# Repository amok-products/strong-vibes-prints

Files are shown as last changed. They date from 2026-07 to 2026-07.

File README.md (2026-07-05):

# Strong Vibes Prints

Parametric [build123d](https://build123d.readthedocs.io/) (Python CAD) parts for
mounting a massager, all sharing one mating interface: **Strong Vibes Connect**.
A keyed rhombus/diamond boss (MALE) plugs into a matching diamond socket (FEMALE)
and is clamped by a single 1/4"-20 camera/tripod screw. The interface is defined
exactly once in the `strongvibes` package (`DIA_A`, `DIA_B`, `BAND_DEPTH`) and
every part imports it, so the connection can never drift — any boss plugs into any
socket, forever.

Part of the [**Strong Vibes**](https://github.com/amok-products/strong-vibes)
open builder program by [Europe Magic Wand®](https://europemagicwand.com/strong-vibes-builder).

> **Interactive 3D:** spin every part in your browser at
> **[amok-products.github.io/strong-vibes-prints](https://amok-products.github.io/strong-vibes-prints/)**.

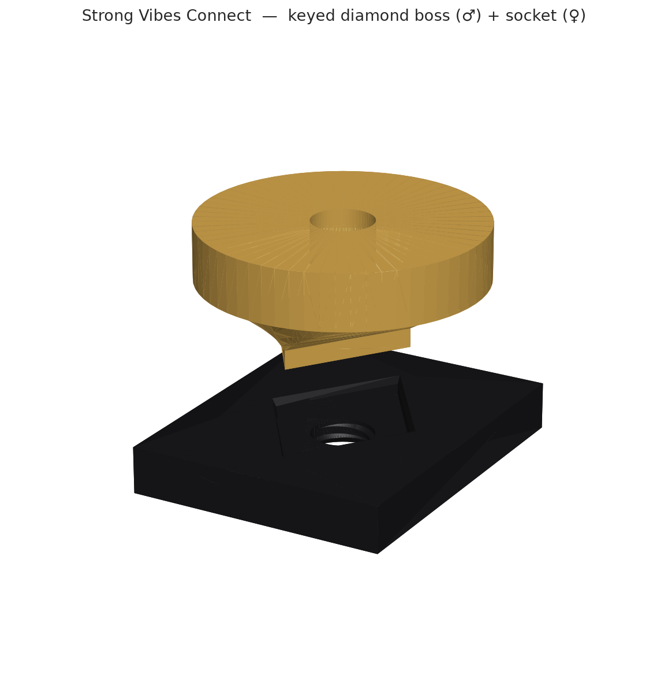
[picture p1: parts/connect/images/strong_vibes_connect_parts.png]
Strong Vibes Connect


---

## Parts

| Part | Role | Description | Folder |
|---|---|---|---|
| **Holder** | MALE | Snap-fit device holder with a Strong Vibes Connect diamond boss. | [`parts/holder/`](parts/holder/) |
| **Connect** | both | Bench-test set: `strong_vibes_socket_180` + `strong_vibes_socket_30` + a male test boss — print these to validate the interface. | [`parts/connect/`](parts/connect/) |

Everything mates through **Strong Vibes Connect**, so these parts interoperate
with any other part built to the standard.

---

## Print a part

These parts are **parametric source** — you build exactly the fit you want.
Blessed ready-to-print exports land in `parts/<part>/release/` as they're cut; if
a `release/` folder is empty, build from source (below) to generate the files.

1. **Preview first.** Spin any part in the
   [interactive 3D viewer](https://amok-products.github.io/strong-vibes-prints/).
2. **Get an export.** Grab a `.stl` (drop straight into a slicer) or `.step`
   (solid model to re-orient/tweak) from `parts/<part>/release/`, or build one
   (see [Build from source](#build-from-source) and [`EXPORTING.md`](EXPORTING.md)).
3. **Slice it** in **Bambu Studio** or **PrusaSlicer**.
4. **Material** — the holder is for **Europe Magic Wand®** models, tested in Bambu
   Lab **TPU for AMS (68D)** or **PLA Tough**; ordinary PLA will crack. For a perfect
   holder fit, add a **4 cm strip of Bambu Lab non-slip tape** to the lower back.
   Sockets print fine in PLA Tough.
5. **Orientation:** print the holder boss horizontal / device axis vertical, as
   exported.

The joint is assembled with one **1/4"-20 × 9–10 mm** camera/tripod screw (Bambu
Lab). With `FEMALE_THREAD` on, the socket is tapped so the screw stays captive.

---

## The Strong Vibes Connect interface

A keyed **diamond (rhombus) boss** seats flat into a matching **diamond socket**
and is clamped by a **1/4"-20 screw** down the joint axis. The diamond is keyed
(long axis ≠ short axis), so the boss seats in a single orientation (mod 180°).

The standard is the constant cross-section of the diamond, defined once in
`strongvibes/`:

- `DIA_A = 11.322 mm` — long half-diagonal
- `DIA_B = 7.759 mm` — short half-diagonal
- `BAND_DEPTH = 2.0 mm` — the constant-section band the socket grips
- **1/4"-20** thread spec — `THREAD_MAJOR = 6.35`, `THREAD_PITCH = 1.27`

Two socket variants exist:

- **`strong_vibes_socket_180`** — keyed single-orientation pocket (the default).
  One diamond, one way in.
- **`strong_vibes_socket_30`** — a star pocket (the diamond unioned every 30°)
  that accepts the boss every 30° for **stepwise rotational mounting**.

Every part imports these from the `strongvibes` package, so the connection is
inherited, never re-derived. Change the standard in one place and every part
follows. The interface is published as the
[**Strong Vibes Connect** standard](https://github.com/amok-products/strong-vibes/blob/main/connect/strong-vibes-connect.md)
in the umbrella repo.

---

## Build from source

The parts are real Python — open one, change a parameter, and watch the 3D model
update live.

1. **Python + dependencies.** Install **Python 3.13** (the project pins
   `>=3.13,<3.14`), then:

   ```bash
   python3.13 -m venv .venv
   source .venv/bin/activate            # Windows: .venv\Scripts\activate
   pip install -r requirements.txt
   pip install -e .                     # wires up the shared `strongvibes` package
   ```

2. **OCP CAD Viewer.** Install the **OCP CAD Viewer** VS Code extension. It pairs
   with the `ocp_vscode` package (already in `requirements.txt`) and shows the
   live 3D preview on **port 3939**. Viewer settings (autostart, port, dark
   theme, axes, grid) are committed in [`.vscode/settings.json`](.vscode/settings.json).

3. **Run & export.** Open a part's `.py`, Run it, and the live 3D preview updates
   in the OCP CAD Viewer. A plain run previews only; prefix `SV_EXPORT=1` to also
   write `.step`, `.stl`, and `.3mf` to the gitignored **`build/`** working dir
   (via `strongvibes.build_path()`). Slice the result in Bambu Studio /
   PrusaSlicer. See [`EXPORTING.md`](EXPORTING.md) for the full preview/export
   workflow and how release files are blessed.

   ```bash
   python parts/holder/strong_vibes_holder.py               # preview only
   SV_EXPORT=1 python parts/holder/strong_vibes_holder.py   # also write build/
   ```

   > **3MF note:** for threaded parts the `.3mf` write is best-effort —
   > `lib3mf`'s strict manifold check can reject the helical thread mesh even
   > when the solid is valid. Use the **`.stl`** or **`.step`** (slicers re-mesh
   > fine).

### Modify with an AI assistant

The parts are parametric, so natural-language edits work well. A realistic prompt:

> *"In `parts/holder/strong_vibes_holder.py`, make the boss buttress taller for
> strength — set `boss_aspect` to 1.4 — without changing the Strong Vibes Connect
> mating diamond. Then rebuild and confirm it's valid."*

`boss_aspect` (default `1.5`) stretches only the structural flare **behind** the
diamond band; the mating diamond stays the standard `DIA_A` / `DIA_B`, so the
connection never changes.

> **Locked:** the mating diamond (`DIA_A`, `DIA_B`, `BAND_DEPTH`) is the shared
> standard and must **not** change in a single part — that would break
> compatibility with every other part. Changing it is a repo-wide interface event
> (see [`AGENTS.md`](AGENTS.md)).

---

## Repo layout

```
strongvibes/             shared library = the Strong Vibes Connect standard (install: pip install -e .)
parts/holder/            strong_vibes_holder.py — snap-fit device holder, MALE diamond boss
parts/connect/           connect_test.py — bench-test set: strong_vibes_socket_180 + strong_vibes_socket_30 + strong_vibes_boss
  parts/<part>/images/   committed renders
  parts/<part>/release/  committed STL/STEP users download (no build needed)
docs/                    interactive 3D landing page (GitHub Pages) + the .glb models it loads
build/                   gitignored working dir — exports land here while iterating
AGENTS.md                versioning + commit conventions for parts
```

---

## Licensing

- The parametric build123d **source and the models it generates** are licensed
  **[CC-BY-4.0](LICENSE)** — free to use, adapt, and print, including
  commercially, with attribution.
- Third-party dependencies keep their own licenses — see [`ATTRIBUTION.md`](ATTRIBUTION.md).
- The **names** ("Strong Vibes", "Europe Magic Wand®") are governed by
  [`TRADEMARK.md`](TRADEMARK.md).

See [`DISCLAIMER.md`](DISCLAIMER.md) before building or using anything. Versioning
and commit conventions live in [`AGENTS.md`](AGENTS.md).

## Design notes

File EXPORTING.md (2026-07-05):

# Exporting parts

Every part is a parametric build123d script. There are exactly **two ways to run
one**, selected by the `SV_EXPORT` environment variable — no file editing:

| Workflow | Command | What it does |
|---|---|---|
| **Preview** (default) | `python parts/<part>/<file>.py` | Builds the solid, prints validity + interface dims, shows it live in the OCP CAD Viewer. **Writes no files.** |
| **Export** | `SV_EXPORT=1 python parts/<part>/<file>.py` | Same build, and also writes `.step` + `.stl` (holder: best-effort `.3mf` too) into the gitignored **`build/`** dir. |

`SV_EXPORT` is read once at startup: unset (or anything other than `1`) means
preview-only. This is why importing a part module — or running it in CI — never
opens a viewer and never writes files.

First set up the environment once (see
[Build from source](README.md#build-from-source)):

```bash
python3.13 -m venv .venv
source .venv/bin/activate            # Windows: .venv\Scripts\activate
pip install -r requirements.txt
pip install -e .                     # wires up the shared `strongvibes` package
```

## Preview (no files)

```bash
python parts/holder/strong_vibes_holder.py     # snap-fit device holder (MALE boss)
python parts/connect/connect_test.py           # socket_180 + socket_30 + test boss
```

Each run prints the part's volume, `is_valid`, and the locked interface dims
(`DIA_A` / `DIA_B` / `BAND_DEPTH`) so you can confirm the build before exporting.
With the **OCP CAD Viewer** VS Code extension running (port 3939) the model
appears live; without a viewer the run still completes — it just skips the
preview.

## Export to `build/`

```bash
SV_EXPORT=1 python parts/holder/strong_vibes_holder.py
SV_EXPORT=1 python parts/connect/connect_test.py
```

Files land in the repo-root **`build/`** working dir (via
`strongvibes.build_path()`), which is gitignored — export freely, nothing is
committed by accident:

- `build/strong_vibes_holder.step` / `.stl`
- `build/strong_vibes_socket_180.step` / `.stl`
- `build/strong_vibes_socket_30.step` / `.stl`
- `build/strong_vibes_boss.step` / `.stl`

Slice the `.stl` in **Bambu Studio** / **PrusaSlicer**, or open the `.step` to
re-orient or tweak first.

> **3MF note:** for threaded parts the `.3mf` write is best-effort — `lib3mf`'s
> strict manifold check can reject the helical thread mesh even when the solid is
> valid. This is expected; use the `.stl` or `.step` (slicers re-mesh fine).

## Bless a release (maintainers)

Ready-to-print files users download without building live in
`parts/<part>/release/`, **named with the part's `__version__`** (read it at the
top of the script). To cut a release:

1. Export to `build/` with `SV_EXPORT=1` and confirm the printed `is_valid` is
   `True` and the interface dims are unchanged.
2. Copy the validated `.step` + `.stl` into the part's `release/` folder, renamed
   with the version — e.g. for holder `__version__ = "2.0.0"`:

   ```bash
   cp build/strong_vibes_holder.step parts/holder/release/strong_vibes_holder-2.0.0.step
   cp build/strong_vibes_holder.stl  parts/holder/release/strong_vibes_holder-2.0.0.stl
   ```

`build/` is never committed; `parts/**/release/` is (the `.gitignore` ignores
`*.stl` / `*.step` globally **except** under `release/`). See
[`AGENTS.md`](AGENTS.md) for the full versioning + release conventions.

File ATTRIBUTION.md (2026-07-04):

# Attribution

The parametric parts in this repository (the build123d source and the models it
generates) are licensed **CC-BY-4.0** — see [`LICENSE`](LICENSE). This file credits
the third-party works this repo builds on; each keeps its **own** license.

## The CAD builds on

| Work | License | Used for |
|---|---|---|
| [build123d](https://github.com/gumyr/build123d) | Apache-2.0 | the Python CAD framework the parts are written in |
| [OCP](https://github.com/CadQuery/OCP) (`cadquery-ocp` bindings) | Apache-2.0 | the Python bindings to the geometry kernel |
| [OpenCASCADE (OCCT)](https://dev.opencascade.org/), bundled by `cadquery-ocp` | LGPL-2.1 + OCCT exception | the geometry kernel behind build123d |
| [bd_warehouse](https://github.com/gumyr/bd_warehouse) | Apache-2.0 | thread modelling (the 1/4"-20 helical thread) |
| [OCP CAD Viewer](https://github.com/bernhard-42/vscode-ocp-cad-viewer) (`ocp_vscode`, `ocp-tessellate`) | Apache-2.0 | the live VS Code 3D preview |

The complete, pinned Python dependency set is in
[`requirements.txt`](requirements.txt); each package retains its own upstream
license.

## The landing page uses

| Work | License | Used for |
|---|---|---|
| [`<model-viewer>`](https://github.com/google/model-viewer) by Google | Apache-2.0 | the interactive 3D part previews in `docs/` (loaded from Google's CDN) |
| [Inter](https://github.com/rsms/inter) & [JetBrains Mono](https://github.com/JetBrains/JetBrainsMono) fonts | SIL OFL-1.1 | the landing-page typography (loaded from Google Fonts) |

## Standard

The **Strong Vibes Connect** dimensions (`DIA_A`, `DIA_B`, `BAND_DEPTH`, thread
spec) in `strongvibes/strong_vibes_connect.py` are the source of truth for the
[Strong Vibes Connect standard](https://github.com/amok-products/strong-vibes/blob/main/connect/strong-vibes-connect.md)
published in the umbrella repo.

If you believe an attribution is missing or incorrect, please open an issue.

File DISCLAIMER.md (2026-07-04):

# Disclaimer

**Read this before printing or using anything from this project.**

- **Adults only (18+).** This project relates to adult products. It is not
  intended for minors.

- **Hobbyist parts — build and use at your own risk.** This repository provides
  open-source, parametric mechanical designs and 3D-printable parts that mount
  and interface with a massager. You are responsible for the parts you print,
  assemble, and use, and for doing so safely and legally.

- **Not a medical device.** These designs and any parts printed from them are
  **not** medical devices. They are not intended to diagnose, treat, cure, or
  prevent any disease or condition, and make no therapeutic or health claims.
  Consult a qualified professional for medical advice.

- **Safety.** Use **body-safe materials** for anything printed that contacts skin,
  keep printed parts within their mechanical limits, verify fit before relying on
  a mount, and stop use if anything cracks, deforms, or causes discomfort or pain.

- **No warranty.** The designs are provided "AS IS", without warranty of any kind,
  to the fullest extent permitted by law. See the [`LICENSE`](LICENSE) (CC-BY-4.0)
  for the full disclaimer of warranty and limitation of liability. The authors and
  contributors are not liable for any damages or injury arising from use of these
  designs or any parts made from them.

By using anything from this project you acknowledge and accept these terms.

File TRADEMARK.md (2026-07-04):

# Trademark & Branding Policy

This policy governs the **names and brands** of the Strong Vibes program. It is
separate from the content and code licenses. The documents and standards in this
repository are licensed under **CC-BY-4.0** (see [`LICENSE`](LICENSE)); the
reference code repositories are licensed under **Apache-2.0**. Neither license
grants trademark rights — this document covers the names. Together they
implement the program's intent: **the specs and code are free to use, including
commercially — but the names travel with accreditation.**

## The marks

- **Europe Magic Wand®** is a **registered trademark** of AMOK / Europe Magic Wand.
- **"Strong Vibes"**, **"Strong Vibes Protocol"**, **"Strong Vibes Connect"**,
  **"Strong Vibes Playapp"**, and **"Strong Vibes Knob Control"** are
  **(unregistered) trademarks ™** of AMOK / Europe Magic Wand.

None of the "Strong Vibes" marks are registered. Do not represent them as
registered trademarks.

## What the licenses give you

Under **CC-BY-4.0** (this repo's specs and docs) you may share and adapt the
material, including commercially, provided you give attribution as the license
requires. Under **Apache-2.0** (the reference code repositories) you may use,
modify, distribute, and commercialize the code, subject to that license
(including preserving the `NOTICE` file). CC-BY-4.0 and Apache-2.0 both stop
short of granting trademark rights — this document states how the names may be
used.

## Grant to use the names

You **may**:

- Use the specifications and code freely under their respective licenses.
- Make **factual compatibility / interoperability statements**, e.g.
  "implements the Strong Vibes Protocol by europemagicwand.com" or
  "compatible with Strong Vibes Connect" or "works with Europe Magic Wand®
  devices", provided the statement is truthful and does not imply endorsement.
- Keep a "Strong Vibes" product name **if** you preserve the accreditation below.

You **must**, when using a "Strong Vibes" name to identify a product or a fork:

- Use the accreditation form **"Strong Vibes X by europemagicwand.com"**
  (for example, "Strong Vibes Playapp by europemagicwand.com"), preserving the
  `by europemagicwand.com` credit.
- Preserve the required attribution (CC-BY-4.0 attribution for specs/docs; the
  `NOTICE` file for code) in distributions.
- Attach the ® symbol only to "Europe Magic Wand®" (the registered mark), where
  the parent product is named. Never attach ® to any "Strong Vibes" mark — use ™
  where a mark is shown. This does not waive the accreditation form required
  above.

You **may not**:

- Present a modified or non-conforming fork as the official project, or imply
  endorsement by AMOK / Europe Magic Wand.
- Claim any "Strong Vibes" mark as a registered trademark.
- Use the marks in a way that is misleading or disparaging.

## Non-conforming forks

AMOK / Europe Magic Wand **reserves the right to require a fork that does not
conform to this policy to remove or change the "Strong Vibes" and "Europe Magic
Wand®" names** (i.e. to rebrand). This does not affect your rights to the specs
or code themselves under their licenses — only the use of the names.

## Questions

For permission beyond this policy, or clarification, contact the maintainers via
the channel listed in [`SECURITY.md`](SECURITY.md).

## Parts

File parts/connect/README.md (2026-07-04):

# Connect (`connect_test.py`)

The bench-test pair for the **Strong Vibes Connect** standard — print these to validate the interface itself. It exercises both socket variants against a male test boss, all built from the locked standard in `strongvibes`.

Strong Vibes Connect parts

## What's in it

- **`strong_vibes_socket_180`** — FEMALE, keyed diamond pocket: accepts the boss in **one** orientation (mod 180°). The default socket.
- **`strong_vibes_socket_30`** — FEMALE, star pocket (the diamond unioned every 30°): accepts the boss **every 30°** for stepwise rotational mounting.
- **`strong_vibes_boss`** — MALE, a stand-in for the holder boss: the diamond (band + flare) on a round base with a real 1/4"-20 internal thread.

Assemble the pair with one **1/4"-20 × 9–10 mm** camera screw (Bambu Lab).

## Key parameters (from `strongvibes/strong_vibes_connect.py`)

| Param | Default | What it does |
|---|---|---|
| `DIA_A` / `DIA_B` | `11.322` / `7.759` | Long / short diamond half-diagonals [mm] — the locked standard. |
| `BAND_DEPTH` | `2.0` | Constant-section band the socket grips [mm]. |
| `CLEAR` | `0.20` | Fit clearance per half-diagonal (0.12 tight … 0.35 loose). |
| `THREAD_CLEAR` | `0.6` | Diametral clearance on the modelled 1/4-20 thread for FDM. |
| `FEMALE_THREAD` | `True` | Tap the socket so the screw stays captive (else a plain clearance bore). |

## Renders

| | |
|--|--|
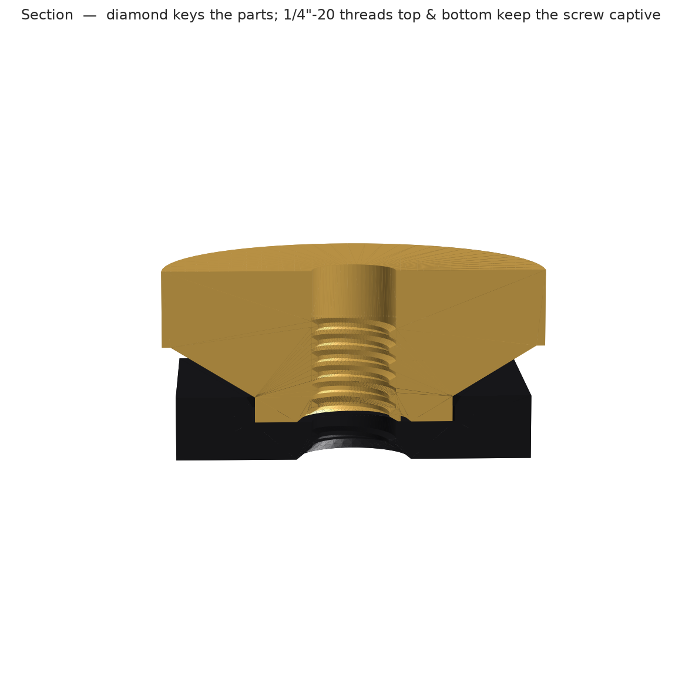
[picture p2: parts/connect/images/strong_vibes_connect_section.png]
Section
| Parts |  |
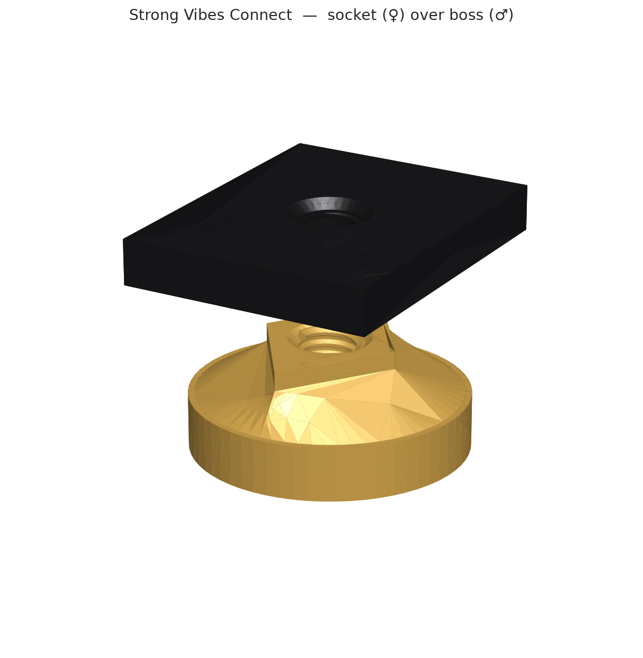
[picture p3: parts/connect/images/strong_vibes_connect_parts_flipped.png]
Parts flipped
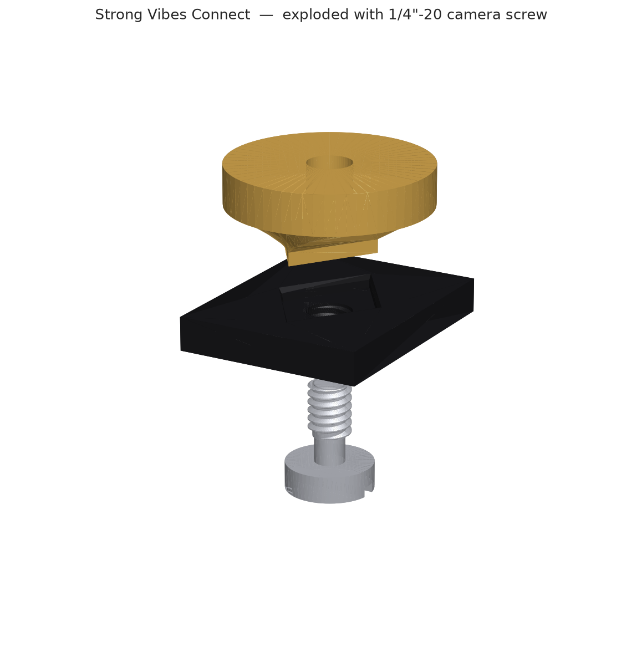
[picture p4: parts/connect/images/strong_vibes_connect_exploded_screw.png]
Exploded with screw
|  |  |

## Preview & export

```bash
python parts/connect/connect_test.py    # live 3D in the OCP CAD Viewer (port 3939)
```

Running the module prints an interface summary (the standard `DIA_A` / `DIA_B` / `BAND_DEPTH` and each part's bounding box). Set `EXPORT = True` (the default is `False`, preview-only) to also write `.step` and `.stl` for each part to the gitignored `build/` dir.

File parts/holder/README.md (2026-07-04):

# Holder (`strong_vibes_holder.py`)

The snap-fit device holder — the **MALE** side of the Strong Vibes Connect. The device clips into the holder, and the holder carries a keyed diamond boss that plugs into any Strong Vibes Connect socket, clamped by a 1/4"-20 screw.

> Spin it in 3D in the [interactive viewer](https://amok-products.github.io/strong-vibes-prints/).

## Role

**MALE** — diamond boss (`DIA_A` / `DIA_B` / `BAND_DEPTH`, imported from `strongvibes`) with a 1/4"-20 internal thread down the boss axis. The mating diamond is the locked standard and is never recomputed here.

## Key parameters

| Param | Default | What it does |
|---|---|---|
| `boss_aspect` | `1.5` | Taller buttress via the flare only (axial Z stretch behind the diamond). The mating diamond stays the standard. |
| `boss_flare` | `7` | How far the boss widens past the diamond onto the body. |
| `boss_fillet` | `10` | Blend radius where the boss meets the wall. |
| `THREAD_CLEAR` | `0.6` | Diametral clearance on the modelled 1/4-20 thread for FDM (raise to loosen). |
| `use_thread` | `True` | Model the helical thread (`False` = plain 5.8 mm self-tap hole). |
| `QUILT` | `True` | Recessed diamond-quilt texture on the outer surface. |

For **Europe Magic Wand®** models. Tested in Bambu Lab **TPU for AMS (68D)** or **PLA Tough** — ordinary PLA will crack. For a perfect fit, add a **4 cm strip of Bambu Lab non-slip tape** to the lower back. Assemble with a **1/4"-20 × 9–10 mm** camera screw (Bambu Lab).

## Preview & export

```bash
python parts/holder/strong_vibes_holder.py     # live 3D in the OCP CAD Viewer (port 3939)
```

Set `EXPORT = True` (already the default) to also write `.step` / `.stl` / `.3mf` to the gitignored `build/` dir. The `.3mf` is best-effort and may be skipped for the threaded mesh — use the `.stl` or `.step`.

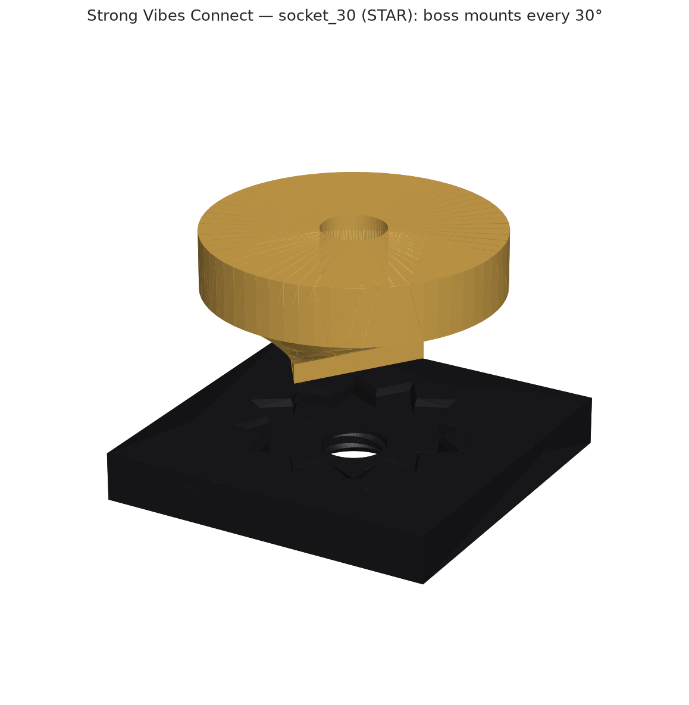
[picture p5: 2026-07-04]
parts/connect/images/strong_vibes_connect_socket_30.png

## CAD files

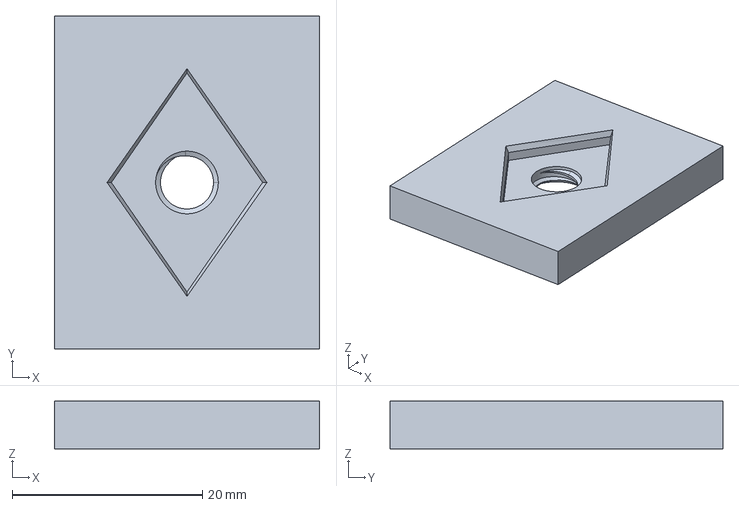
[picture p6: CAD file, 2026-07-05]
parts/connect/release/strong_vibes_socket_180-1.0.0.step
27.9 x 35.0 x 5.00 mm

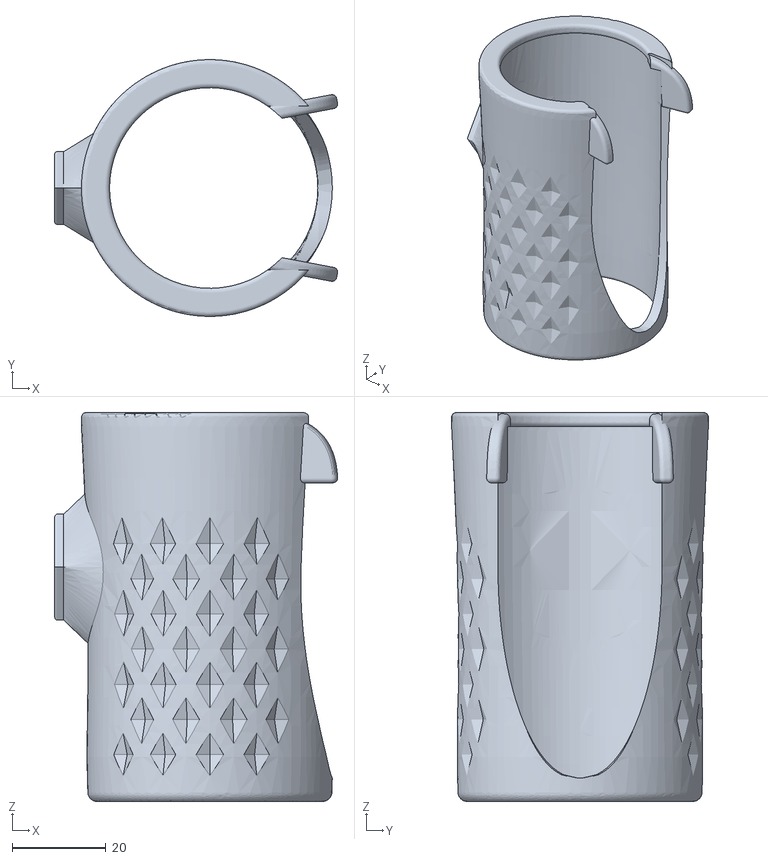
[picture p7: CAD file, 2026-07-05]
parts/holder/release/strong_vibes_holder-2.0.0.stl
60.4 x 54.8 x 83.0

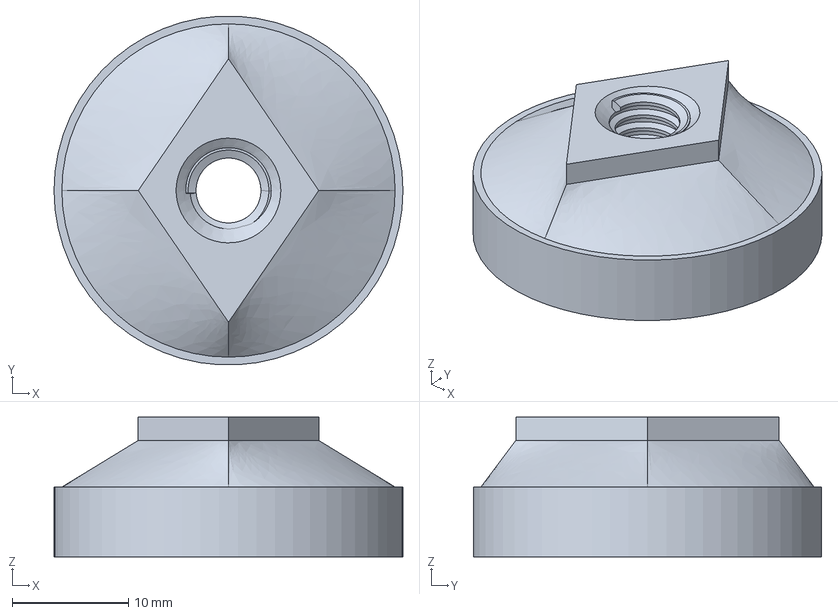
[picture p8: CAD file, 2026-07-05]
parts/connect/release/strong_vibes_boss-1.0.0.step
30.0 x 30.0 x 12.0 mm

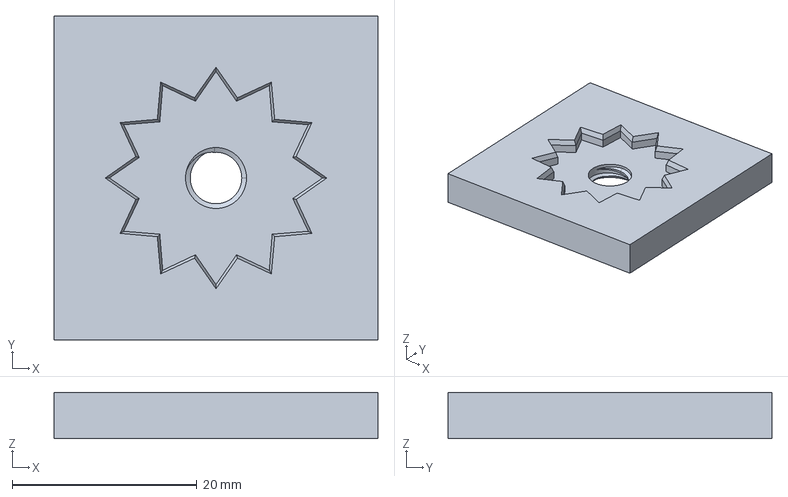
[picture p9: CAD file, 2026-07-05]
parts/connect/release/strong_vibes_socket_30-1.0.0.step
35.0 x 35.0 x 5.00 mm

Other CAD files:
parts/connect/release/strong_vibes_boss-1.0.0.stl
parts/connect/release/strong_vibes_socket_180-1.0.0.stl
parts/connect/release/strong_vibes_socket_30-1.0.0.stl

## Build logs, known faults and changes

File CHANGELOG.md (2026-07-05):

# Changelog

All notable changes to Strong Vibes Prints are documented here. The format is
based on [Keep a Changelog](https://keepachangelog.com); newest first. Individual
parts also carry their own `__version__` (see [`AGENTS.md`](AGENTS.md)).

## [Unreleased]

Tooling & packaging only — **no geometry changes**, so no part `__version__`
bumps and the exported models are identical to 1.0.0.

- **Headless-safe parts.** `strong_vibes_holder.py` now guards its `ocp_vscode`
  import (`try/except`) and runs its preview + export under
  `if __name__ == "__main__"`, matching `connect_test.py`. Running a part with no
  OCP CAD Viewer no longer errors, and merely importing a part module opens no
  viewer and writes no files.
- **`SV_EXPORT` export toggle.** Exporting no longer means hand-editing an
  `EXPORT` constant: a plain run previews only, and
  `SV_EXPORT=1 python parts/<part>/<file>.py` also writes `.step` / `.stl` into
  the gitignored `build/`. New [`EXPORTING.md`](EXPORTING.md) documents both
  workflows; linked from the README.
- **First blessed release files.** `parts/holder/release/` and
  `parts/connect/release/` now hold the version-named `.stl` + `.step` the
  landing page's "STL / STEP files" links serve — `strong_vibes_holder-2.0.0`,
  and `strong_vibes_socket_180` / `strong_vibes_socket_30` / `strong_vibes_boss`
  at `1.0.0`.

## [1.0.0] — 2026-07-04

Initial public release as part of the [Strong Vibes](https://github.com/amok-products/strong-vibes)
open builder program.

- **Strong Vibes Connect** mating standard (`STANDARD_VERSION = 1.0.0`) — keyed
  diamond boss + socket clamped by a 1/4"-20 screw, defined once in the
  `strongvibes` package and imported by every part.
- **Holder** (`strong_vibes_holder.py`) — snap-fit device holder, MALE diamond boss.
- **Connect** bench-test set (`connect_test.py`) — `strong_vibes_socket_180`,
  `strong_vibes_socket_30`, and a male test boss for validating the interface.
- Interactive 3D landing page (GitHub Pages).

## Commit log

2026-07-04 Strong Vibes Prints — initial public release
    Parametric build123d parts sharing the Strong Vibes Connect interface:
    the strong_vibes_holder (MALE) and the socket_180 / socket_30 / boss
    bench-test set. Includes the interactive 3D landing page (GitHub Pages).
2026-07-04 docs: Europe Magic Wand fit notes, 9–10 mm screw, release-folder links
    Holder: note it's for Europe Magic Wand models; tested in Bambu Lab TPU for AMS
    or PLA Tough (ordinary PLA cracks); 4 cm non-slip-tape tip. Set the camera screw to
    1/4"-20 × 9–10 mm. Add STL/STEP release-folder links on the landing page and part cards.
2026-07-05 parts: headless-safe runs + SV_EXPORT toggle; first release files
    Robustness + packaging only — no geometry changes.
    - Guard the holder like connect_test: wrap the ocp_vscode import in
    try/except and move preview + export under `if __name__ == "__main__"`.
    Running a part with no OCP CAD Viewer no longer errors, and importing a
    part module opens no viewer and writes no files.
    - Replace the hand-edited `EXPORT` constant with an `SV_EXPORT` env toggle
    in both exporting scripts: a plain run previews only;
    `SV_EXPORT=1 python parts/<part>/<file>.py` also writes .step/.stl into
    the gitignored build/ dir.
    - Bless the first release files: version-named .stl + .step under each
    part's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
    [strong_vibes_boss-1.0.0.step, strong_vibes_boss-1.0.0.stl, strong_vibes_holder-2.0.0.stl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]
